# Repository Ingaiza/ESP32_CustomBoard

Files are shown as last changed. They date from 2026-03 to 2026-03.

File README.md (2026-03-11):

# Custom ESP32-C3 Development Board

## Overview
This repository contains the KiCad PCB design files for a custom development board powered by the ESP32-C3 microcontroller. This board integrates essential environmental sensing, audio input, and power management features. It serves as a robust hardware foundation for developing advanced embedded systems and IoT devices.

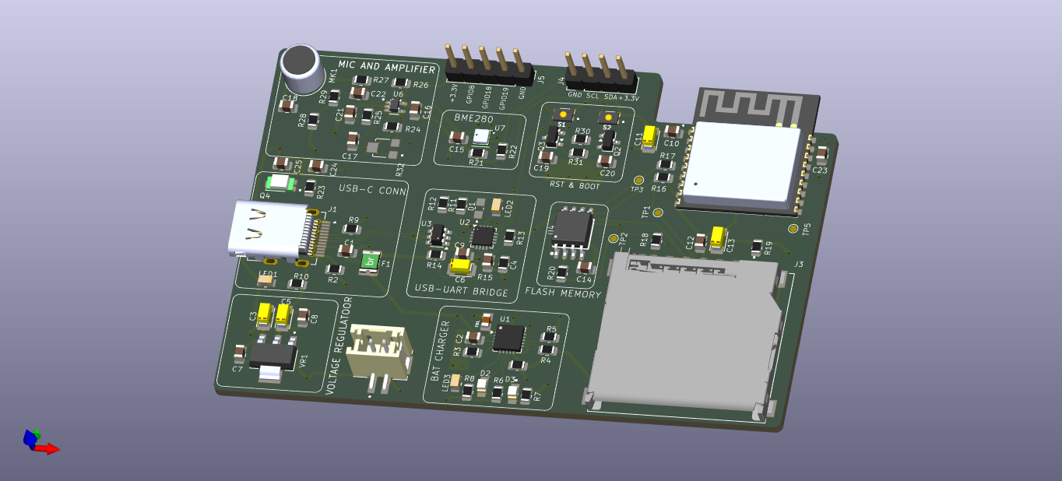
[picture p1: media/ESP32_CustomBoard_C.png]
Board 3D View


## Hardware Features

* **Microcontroller**: Powered by the ESP32-C3-WROOM-02-H4 module, offering Wi-Fi and Bluetooth LE connectivity.
* **Power Management**: 
    * Modern USB-C connector interface.
    * Onboard 3.3V voltage regulation via the LM1117MPX-3.3 LDO.
    * Integrated LiPo battery charging circuit utilizing the MCP73871 IC.
* **USB-to-UART Interface**: Features the CP2102N bridge for reliable serial communication and seamless flashing.
* **Memory & Storage**:
    * External 32Mb (4MB) W25Q32JVSSIQ Flash memory.
    * Dedicated MicroSD card circuit for extensive data logging.
* **Integrated Sensors**:
    * **BME280**: Environmental sensor for capturing temperature, humidity, and barometric pressure data.
    * **TEMT6000**: Ambient light sensor for environmental illumination tracking.
    * **Audio**: Electret microphone (CMC-5042PF-AC) paired with a MAX4466EXK operational amplifier for high-quality audio input.
* **User Interface & Expansion**:
    * Auto-program circuitry equipped with standard Boot and Reset tactile buttons.
    * Dedicated I2C connector optimized for OLED displays.
    * Accessible remaining GPIO breakout headers for rapid prototyping.

## Visuals & Documentation

### Top View
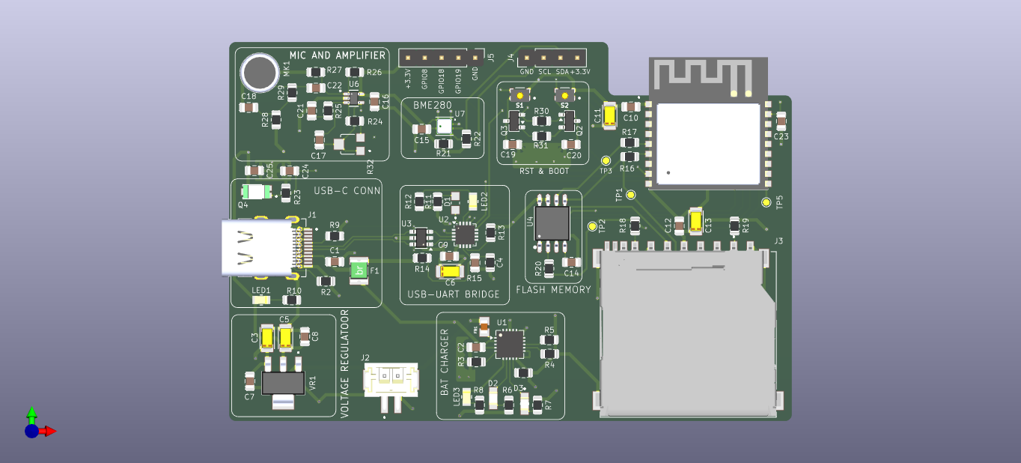
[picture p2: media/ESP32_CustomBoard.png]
Board Top View


### Bottom View Routing
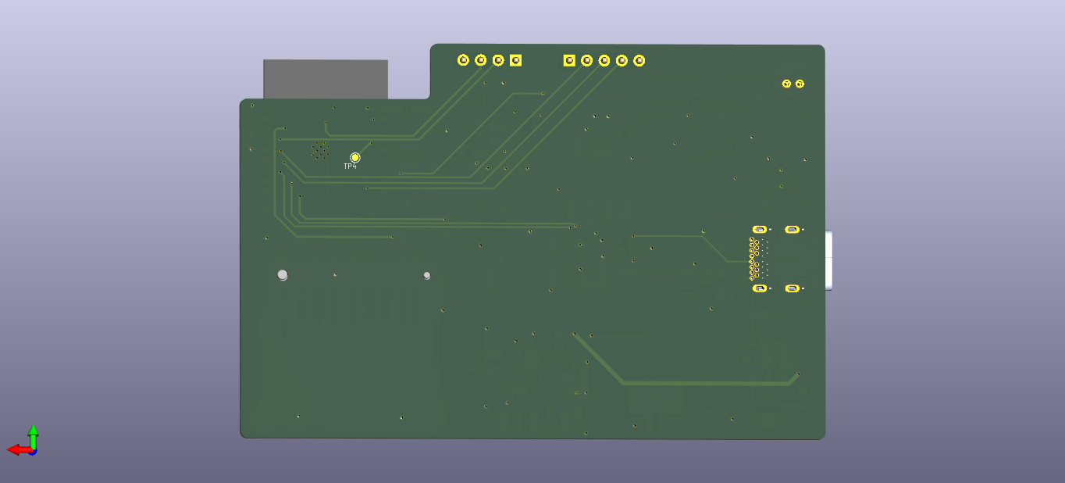
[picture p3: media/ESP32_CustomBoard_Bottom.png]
Board Bottom View


### Schematic
The complete circuit design can be viewed here: [Schematic PDF](media/Shematic.pdf)

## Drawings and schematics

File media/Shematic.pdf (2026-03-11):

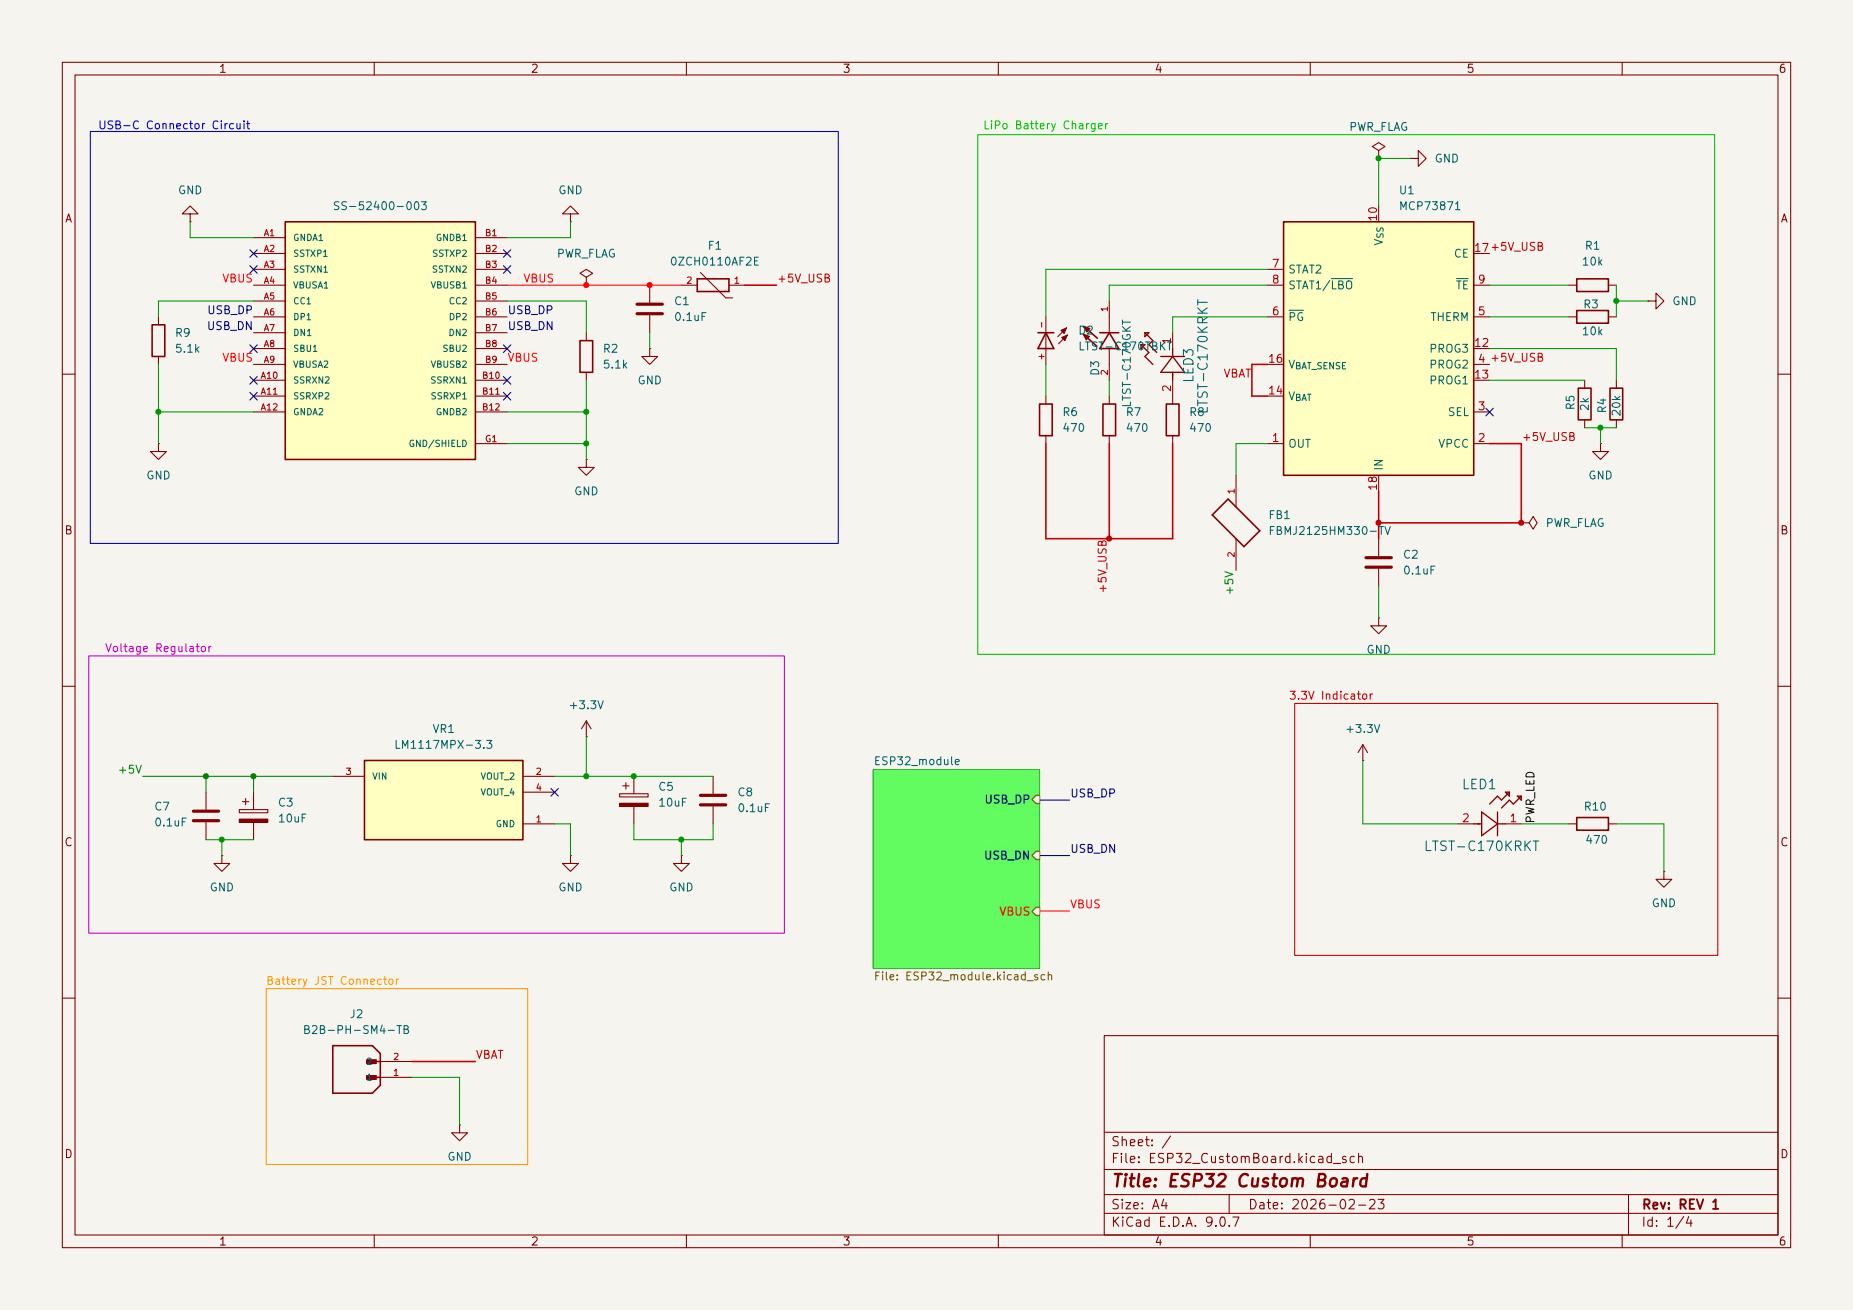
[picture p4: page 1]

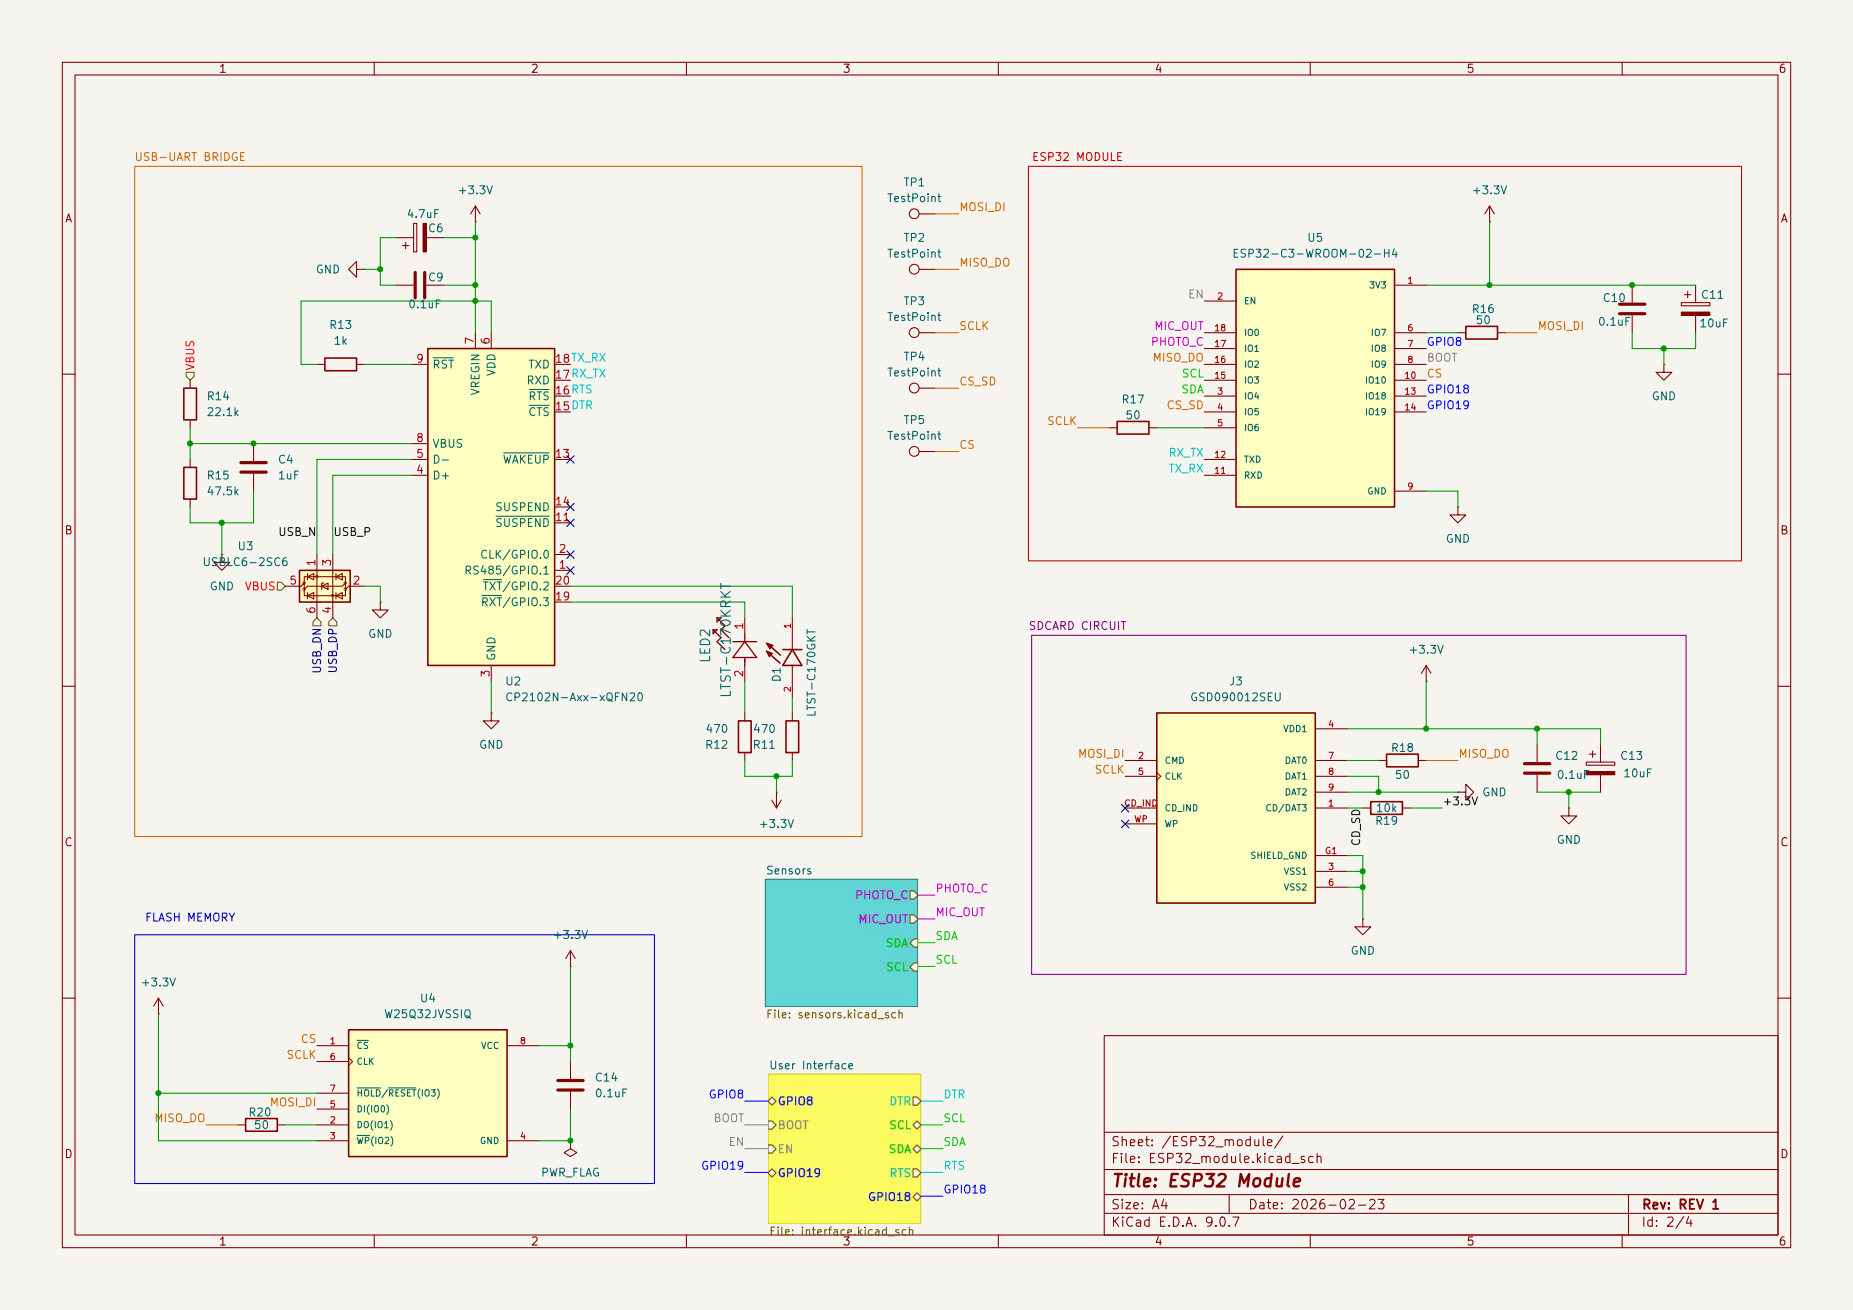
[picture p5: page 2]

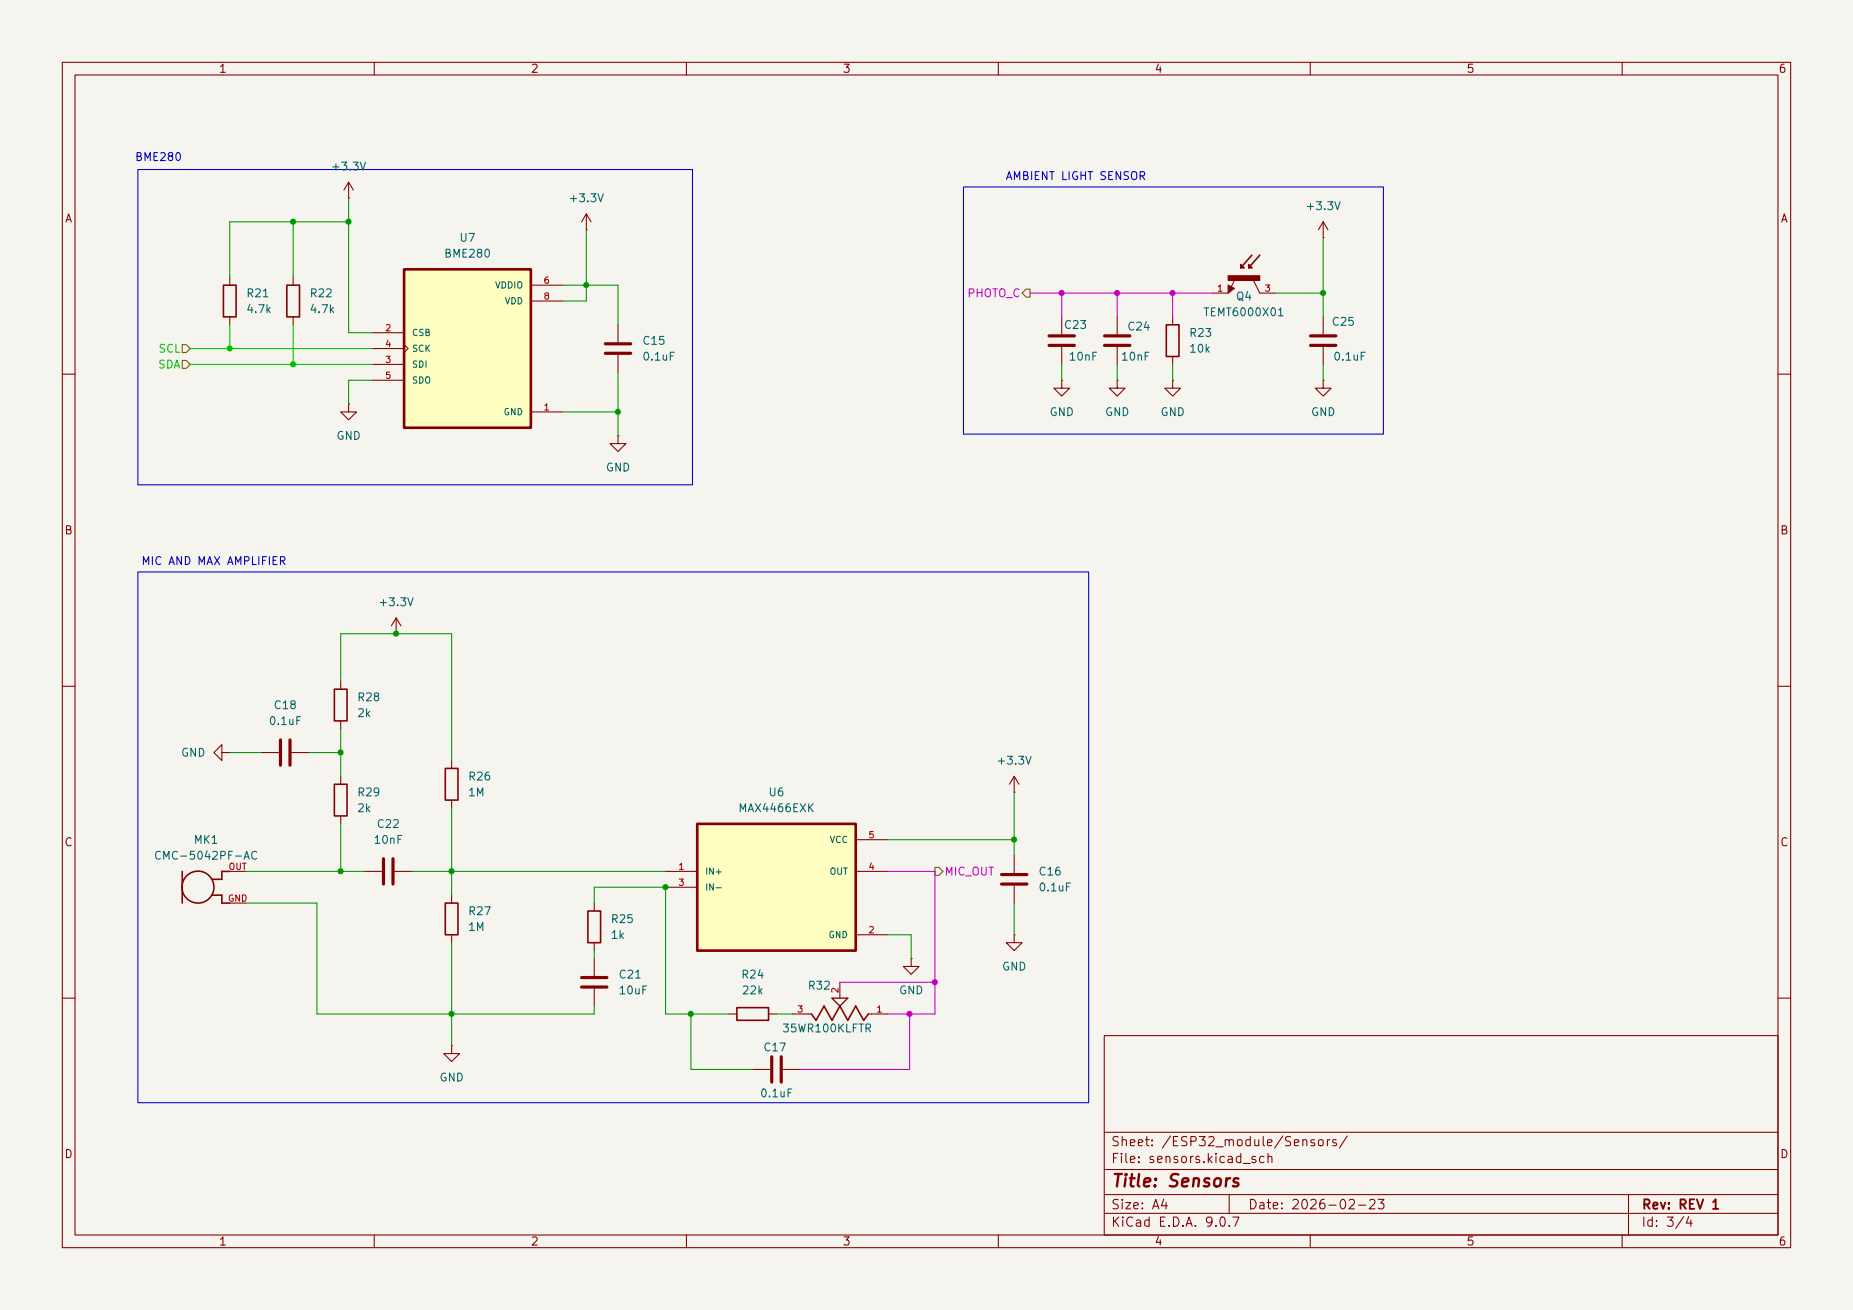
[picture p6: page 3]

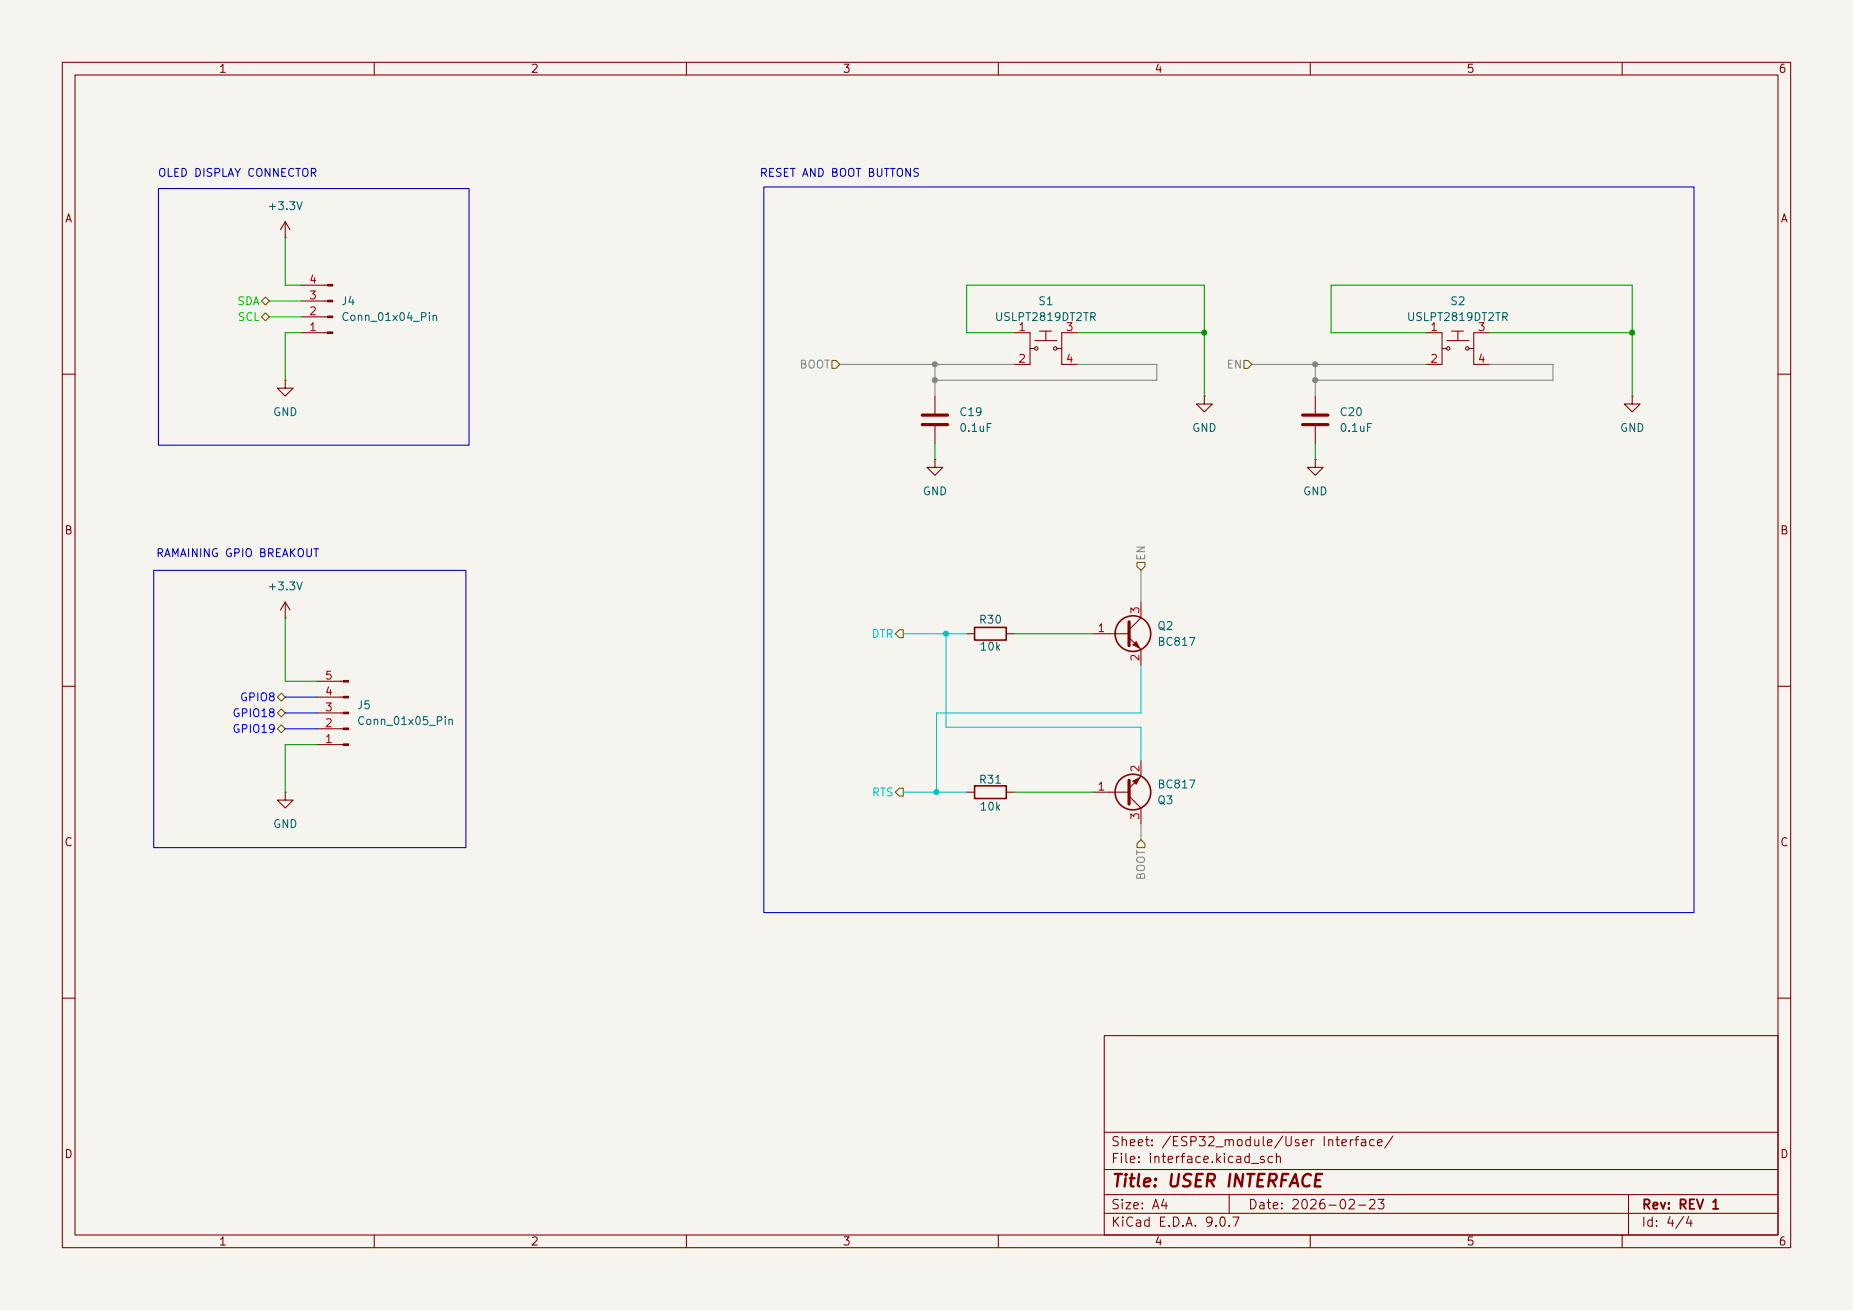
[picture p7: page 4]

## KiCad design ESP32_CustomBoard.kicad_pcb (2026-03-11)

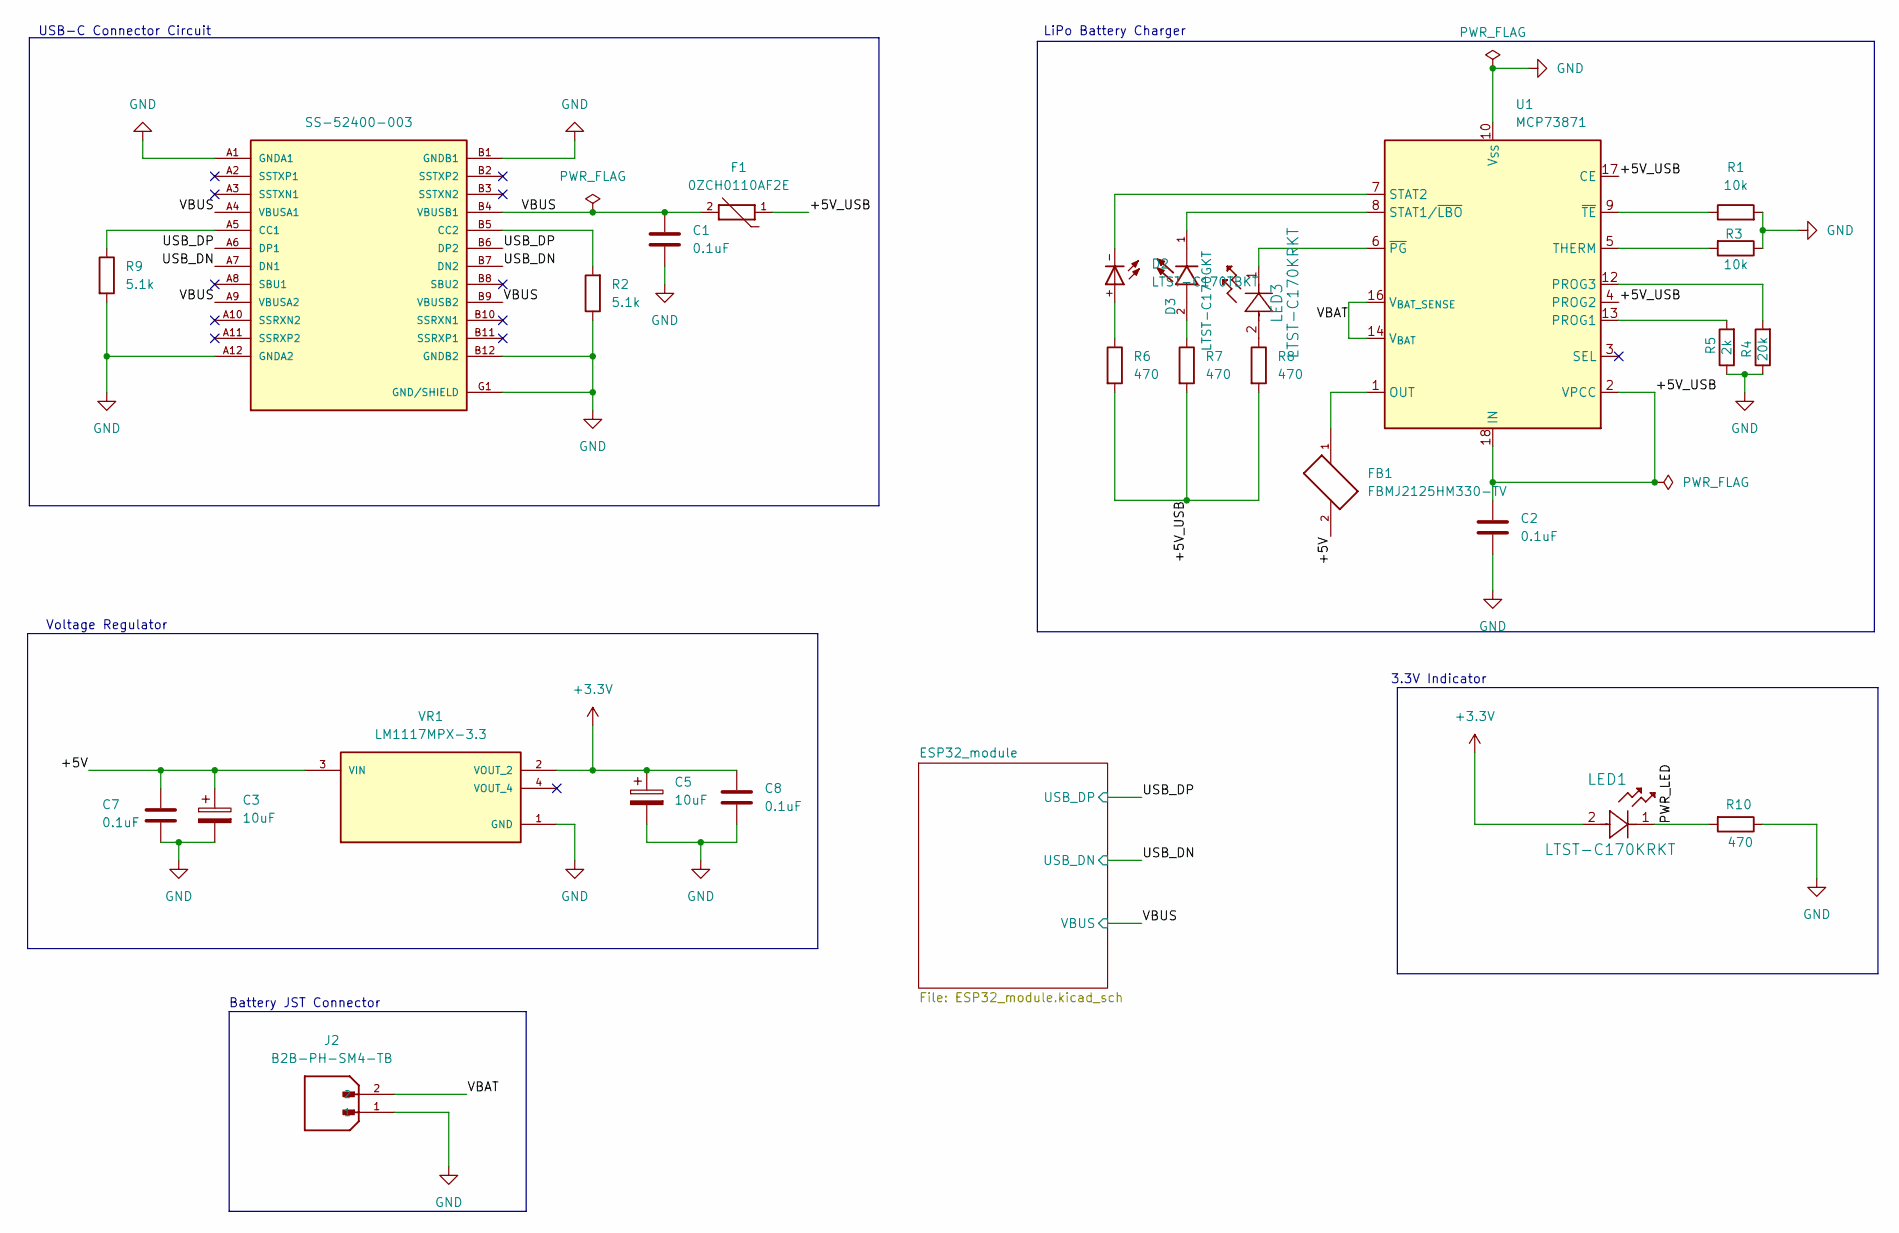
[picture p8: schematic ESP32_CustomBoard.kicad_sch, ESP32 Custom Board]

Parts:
C1, C2, C7, C8: 0.1uF; C_0805_2012Metric
C3, C5: 10uF; RESC3216X125N
D2: LTST-C170TBKT; DIOC200X125X110
D3: LTST-C170GKT; LED_LTST-C170GKT; PARTREV I
F1: 0ZCH0110AF2E; FUSC3225X100N; PARTREV Apr2023
FB1: FBMJ2125HM330-TV; BEADC2012X105N
J1: SS-52400-003; BELFUSE_SS-52400-003; PARTREV A0
J2: B2B-PH-SM4-TB; JST_B2B-PH-SM4-TB; PARTREV N/A
LED1, LED3: LTST-C170KRKT; LED_LTST-C170KRKT_LTO
R1, R3: 10k; R_0805_2012Metric
R2, R9: 5.1k; R_0805_2012Metric
R4: 20k; R_0805_2012Metric
R5: 2k; R_0805_2012Metric
R6, R7, R8, R10: 470; R_0805_2012Metric
U1: MCP73871; QFN-20-1EP_4x4mm_P0.5mm_EP2.5x2.5mm
VR1: LM1117MPX-3.3; VREG_LM1117MPX-3.3; PARTREV O

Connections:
+3.3V: C5.1, C8.1, LED1.2, VR1.2 (VOUT_2); also elsewhere on the board
/+5V: C3.1, C7.1, FB1.2, VR1.3 (VIN)
/+5V_USB: C2.1, F1.1, R6.2, R7.2, R8.2, U1.2 (VPCC), U1.4 (PROG2), U1.17 (CE), U1.18 (IN), U1.19 (IN)
/PWR_LED: LED1.1, R10.2
/USB_DN: J1.A7 (DN1), J1.B7 (DN2); also elsewhere on the board
/USB_DP: J1.A6 (DP1), J1.B6 (DP2); also elsewhere on the board
/VBAT: J2.2, U1.14 (V_{BAT}), U1.15 (V_{BAT}), U1.16 (V_{BAT_SENSE})
/VBUS: C1.1, F1.2, J1.A4 (VBUSA1), J1.A9 (VBUSA2), J1.B4 (VBUSB1), J1.B9 (VBUSB2); also elsewhere on the board
GND: C1.2, C2.2, C3.2, C5.2, C7.2, C8.2, J1.A1 (GNDA1), J1.A12 (GNDA2), J1.B1 (GNDB1), J1.B12 (GNDB2), J1.G1 (GND/SHIELD), J1.G2 (GND/SHIELD), J1.G3 (GND/SHIELD), J1.G4 (GND/SHIELD), J1.S1 (GND/SHIELD), J1.S2 (GND/SHIELD), J1.S3 (GND/SHIELD), J1.S4 (GND/SHIELD), J2.1, R1.2, R2.1, R3.1, R4.1, R5.1, R9.2, R10.1, U1.10 (V_{SS}), U1.11 (V_{SS}), U1.21 (V_{SS}), VR1.1 (GND); also elsewhere on the board
unnamed: D2.+, R6.1
unnamed: D3.2, R7.1
unnamed: FB1.1, U1.1 (OUT), U1.20 (OUT)
unnamed: J1.A5 (CC1), R9.1
unnamed: J1.B5 (CC2), R2.2
unnamed: LED3.2, R8.1
unnamed: R5.2, U1.13 (PROG1)
unnamed: R4.2, U1.12 (PROG3)
unnamed: D3.1, U1.8 (STAT1/~LBO)
unnamed: D2.-, U1.7 (STAT2)
unnamed: R3.2, U1.5 (THERM)
unnamed: LED3.1, U1.6 (~PG)
unnamed: R1.1, U1.9 (~TE)

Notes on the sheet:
USB-C Connector Circuit
Voltage Regulator
LiPo Battery Charger
Battery JST Connector
3.3V Indicator

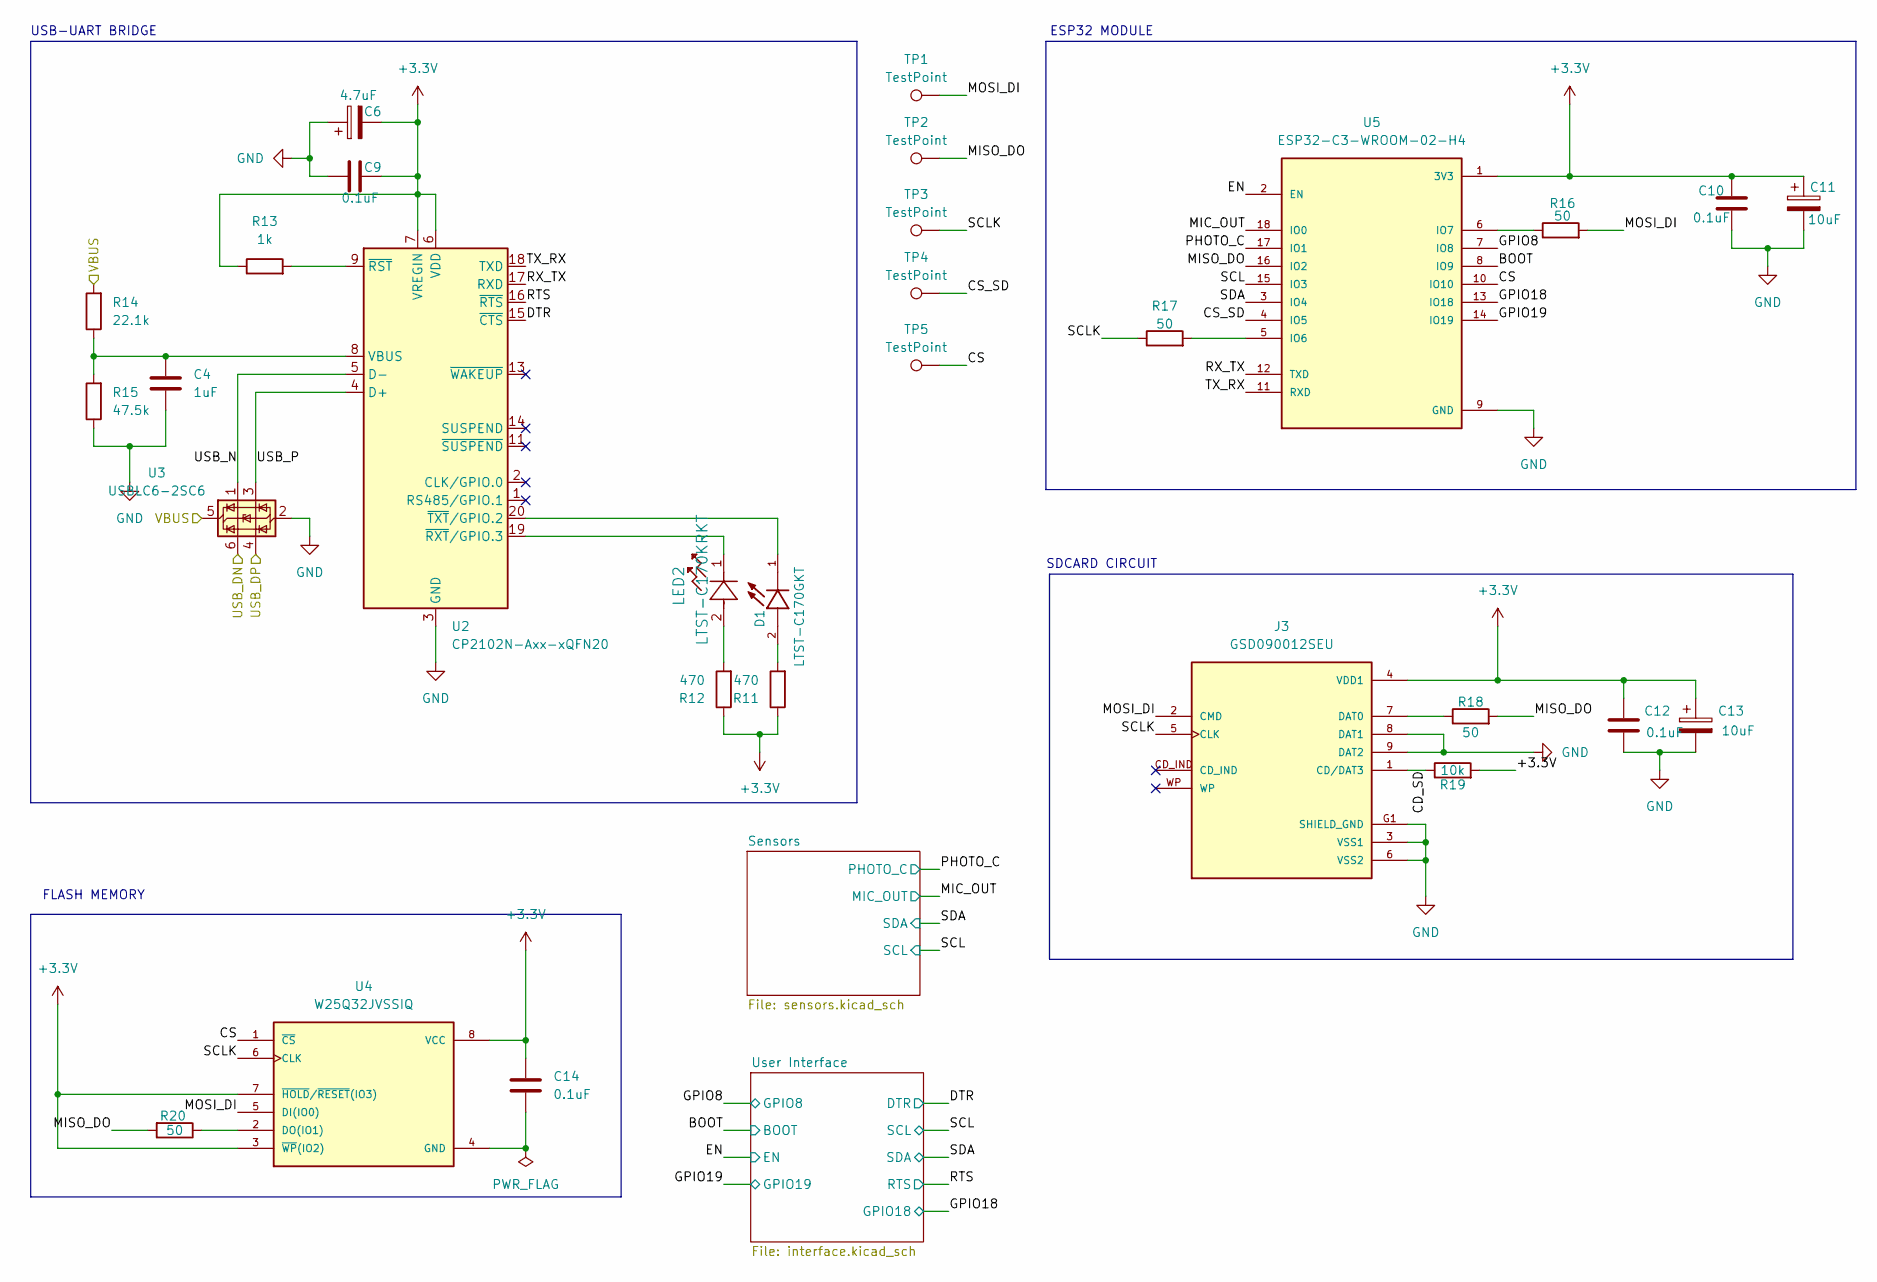
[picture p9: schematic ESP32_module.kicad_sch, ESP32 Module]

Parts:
C4: 1uF; C_0805_2012Metric
C6: 4.7uF; RESC3216X125N
C9, C10, C12, C14: 0.1uF; C_0805_2012Metric
C11, C13: 10uF; RESC3216X125N
D1: LTST-C170GKT; LED_LTST-C170GKT; PARTREV I
J3: GSD090012SEU; AMPHENOL_GSD090012SEU; PARTREV E
LED2: LTST-C170KRKT; LED_LTST-C170KRKT_LTO
R11, R12: 470; R_0805_2012Metric
R13: 1k; R_0805_2012Metric
R14: 22.1k; R_0805_2012Metric
R15: 47.5k; R_0805_2012Metric
R16, R17, R18, R20: 50; R_0805_2012Metric
R19: 10k; R_0805_2012Metric
TP1, TP2, TP3, TP4, TP5: TestPoint; TestPoint_Pad_D1.0mm
U2: CP2102N-Axx-xQFN20; SiliconLabs_QFN-20-1EP_3x3mm_P0.5mm_EP1.8x1.8mm
U3: USBLC6-2SC6; SOT-23-6
U4: W25Q32JVSSIQ; SOIC127P790X216-8N; M_PART_NUMBER W25QXX
U5: ESP32-C3-WROOM-02-H4; MODULE_ESP32-C3-WROOM-02-H4

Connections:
+3.3V: C6.2, C9.2, C10.2, C11.1, C12.1, C13.1, C14.1, J3.4 (VDD1), R11.1, R12.1, R13.1, R19.2, U2.6 (VDD), U2.7 (VREGIN), U4.3 (~WP(IO2)), U4.7 (~HOLD/~RESET(IO3)), U4.8 (VCC), U5.1 (3V3); also elsewhere on the board
/ESP32_module/BOOT: U5.8 (IO9); also elsewhere on the board
/ESP32_module/CD_SD: J3.1 (CD/DAT3), R19.1
/ESP32_module/CS: TP5.1, U4.1 (~CS), U5.10 (IO10)
/ESP32_module/CS_SD: TP4.1, U5.4 (IO5)
/ESP32_module/DTR: U2.15 (~CTS); also elsewhere on the board
/ESP32_module/EN: U5.2 (EN); also elsewhere on the board
/ESP32_module/GPIO8: U5.7 (IO8); also elsewhere on the board
/ESP32_module/GPIO18: U5.13 (IO18); also elsewhere on the board
/ESP32_module/GPIO19: U5.14 (IO19); also elsewhere on the board
/ESP32_module/MIC_OUT: U5.18 (IO0); also elsewhere on the board
/ESP32_module/MISO_DO: R18.2, R20.2, TP2.1, U5.16 (IO2)
/ESP32_module/MOSI_DI: J3.2 (CMD), R16.2, TP1.1, U4.5 (DI(IO0))
/ESP32_module/PHOTO_C: U5.17 (IO1); also elsewhere on the board
/ESP32_module/RTS: U2.16 (~RTS); also elsewhere on the board
/ESP32_module/RX_TX: U2.17 (RXD), U5.12 (TXD)
/ESP32_module/SCL: U5.15 (IO3); also elsewhere on the board
/ESP32_module/SCLK: J3.5 (CLK), R17.1, TP3.1, U4.6 (CLK)
/ESP32_module/SDA: U5.3 (IO4); also elsewhere on the board
/ESP32_module/TX_RX: U2.18 (TXD), U5.11 (RXD)
/ESP32_module/USB_N: U2.5 (D-), U3.1 (I/O1)
/ESP32_module/USB_P: U2.4 (D+), U3.3 (I/O2)
/USB_DN: U3.6 (I/O1); also elsewhere on the board
/USB_DP: U3.4 (I/O2); also elsewhere on the board
/VBUS: R14.2, U3.5 (VBUS); also elsewhere on the board
GND: C4.2, C6.1, C9.1, C10.1, C11.2, C12.2, C13.2, J3.3 (VSS1), J3.6 (VSS2), J3.8 (DAT1), J3.9 (DAT2), J3.G1 (SHIELD_GND), J3.G2 (SHIELD_GND), J3.G3 (SHIELD_GND), J3.G4 (SHIELD_GND), R15.1, U2.3 (GND), U2.12 (GND), U2.21 (GND), U3.2 (GND), U5.9 (GND), U5.19 (GND), U5.20 (GND), U5.21 (GND), U5.22 (GND), U5.23 (GND), U5.24 (GND), U5.25 (GND), U5.26 (GND), U5.27 (GND), U5.28 (GND), U5.29 (GND), U5.30 (GND), U5.31 (GND), U5.32 (GND), U5.33 (GND), U5.34 (GND), U5.35 (GND), U5.36 (GND), U5.37 (GND), U5.38 (GND), U5.39 (GND); also elsewhere on the board
unnamed: D1.2, R11.2
unnamed: J3.7 (DAT0), R18.1
unnamed: LED2.2, R12.2
unnamed: C4.1, R14.1, R15.2, U2.8 (VBUS)
unnamed: R13.2, U2.9 (~RST)
unnamed: LED2.1, U2.19 (~RXT/GPIO.3)
unnamed: D1.1, U2.20 (~TXT/GPIO.2)
unnamed: R20.1, U4.2 (DO(IO1))
unnamed: C14.2, U4.4 (GND)
unnamed: R17.2, U5.5 (IO6)
unnamed: R16.1, U5.6 (IO7)

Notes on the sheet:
SDCARD CIRCUIT
ESP32 MODULE
USB-UART BRIDGE
FLASH MEMORY

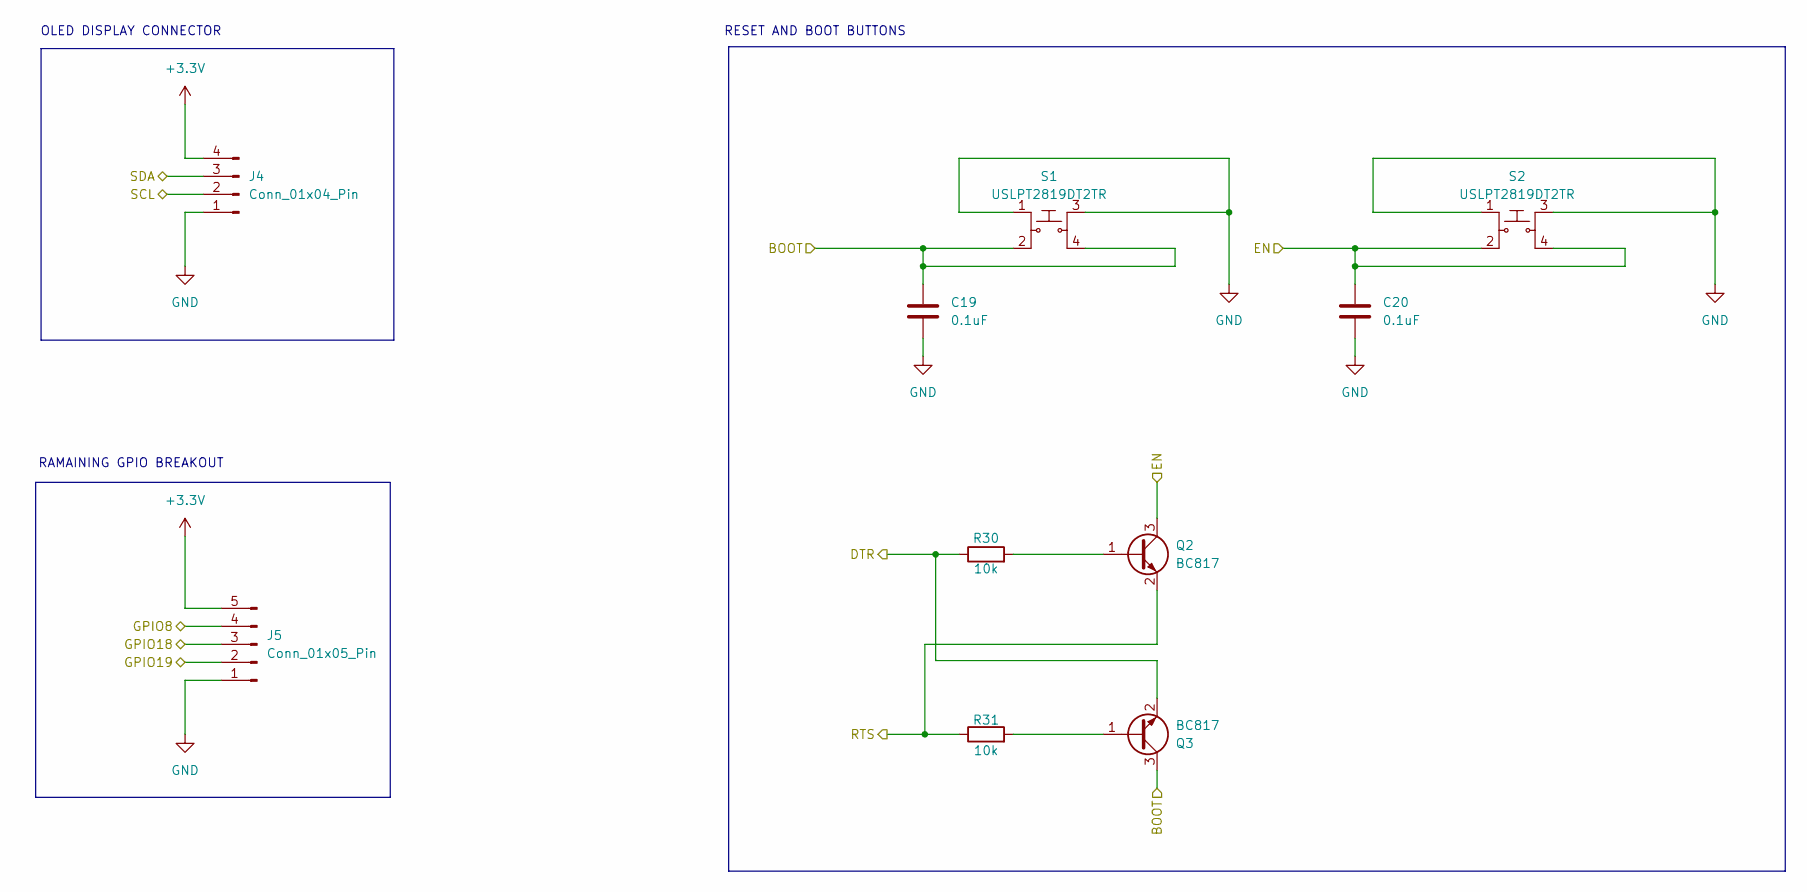
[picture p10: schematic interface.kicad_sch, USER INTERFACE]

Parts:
C19, C20: 0.1uF; C_0805_2012Metric
J4: Conn_01x04_Pin; PinHeader_1x04_P2.54mm_Vertical
J5: Conn_01x05_Pin; PinHeader_1x05_P2.54mm_Vertical
Q2, Q3: BC817; SOT-23
R30, R31: 10k; R_0805_2012Metric
S1, S2: USLPT2819DT2TR; SW_USLPT2819DT2TR; PARTREV P; Digi-Key_PN EG4621CT-ND

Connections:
+3.3V: J4.4, J5.5; also elsewhere on the board
/ESP32_module/BOOT: C19.1, Q3.3 (C), S1.2, S1.4; also elsewhere on the board
/ESP32_module/DTR: Q3.2 (E), R30.1; also elsewhere on the board
/ESP32_module/EN: C20.1, Q2.3 (C), S2.2, S2.4; also elsewhere on the board
/ESP32_module/GPIO8: J5.4; also elsewhere on the board
/ESP32_module/GPIO18: J5.3; also elsewhere on the board
/ESP32_module/GPIO19: J5.2; also elsewhere on the board
/ESP32_module/RTS: Q2.2 (E), R31.1; also elsewhere on the board
/ESP32_module/SCL: J4.2; also elsewhere on the board
/ESP32_module/SDA: J4.3; also elsewhere on the board
GND: C19.2, C20.2, J4.1, J5.1, S1.1, S1.3, S2.1, S2.3; also elsewhere on the board
unnamed: Q2.1 (B), R30.2
unnamed: Q3.1 (B), R31.2

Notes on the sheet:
OLED DISPLAY CONNECTOR
RESET AND BOOT BUTTONS
RAMAINING GPIO BREAKOUT

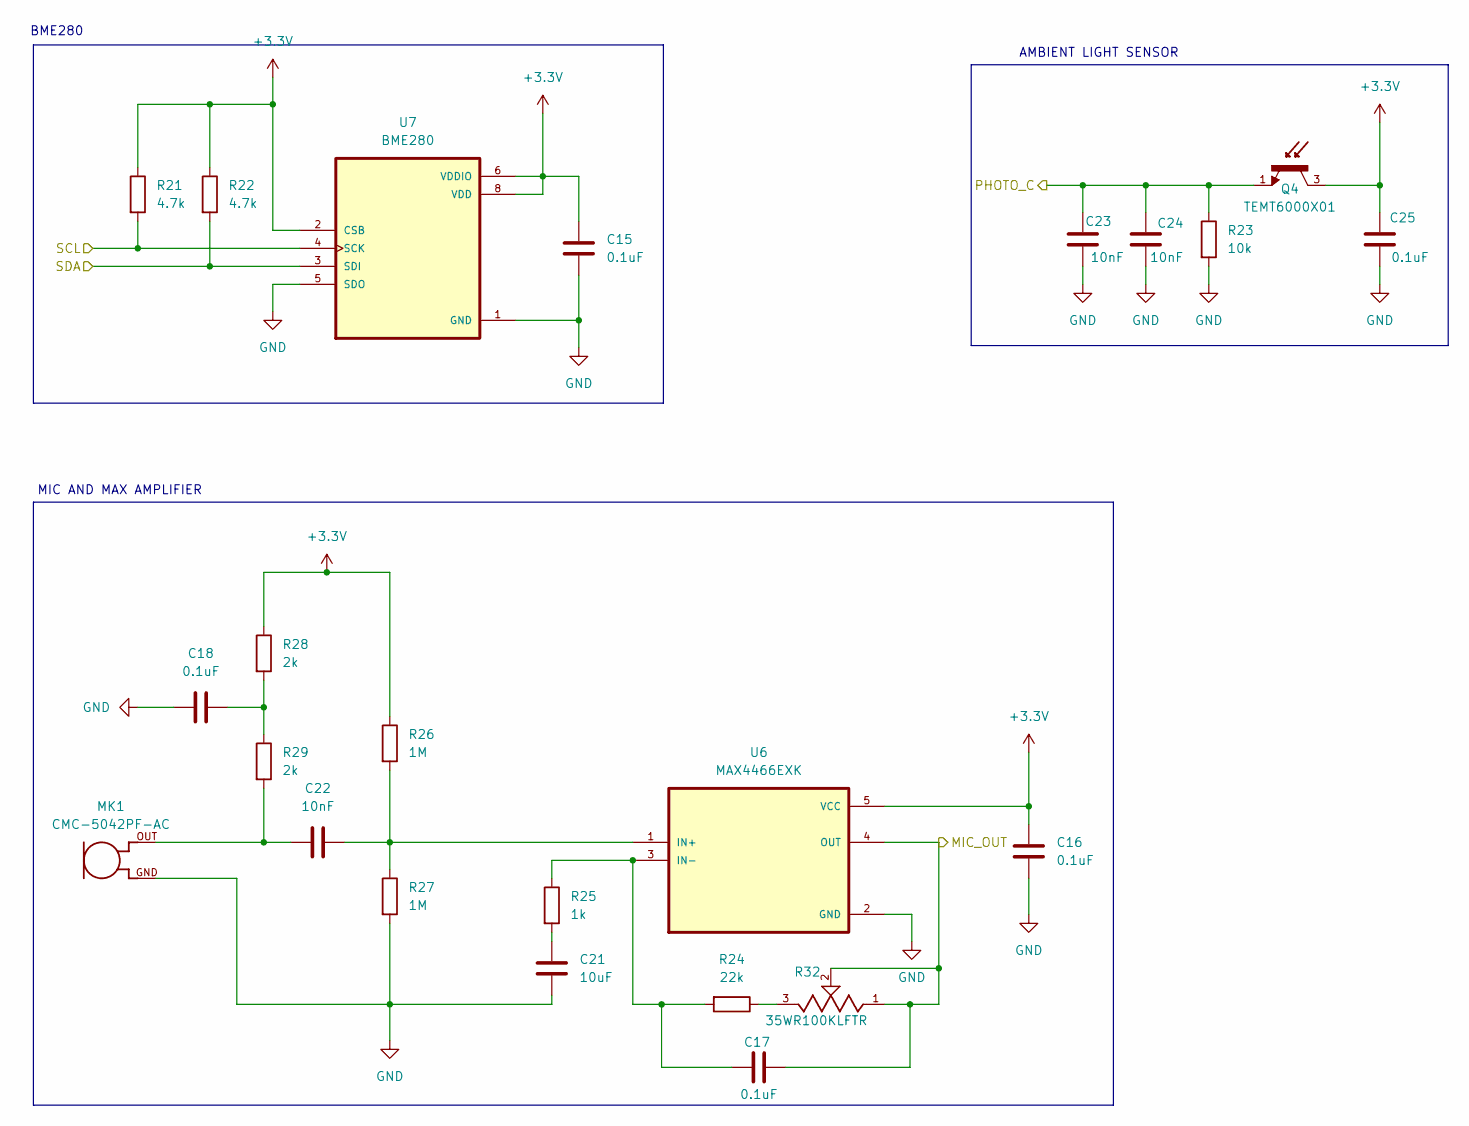
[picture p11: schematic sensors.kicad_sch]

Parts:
C15, C16, C17, C18, C25: 0.1uF; C_0805_2012Metric
C21: 10uF; C_0805_2012Metric
C22, C23, C24: 10nF; C_0805_2012Metric
MK1: CMC-5042PF-AC; CUI_CMC-5042PF-AC
Q4: TEMT6000X01; TRANS_TEMT6000X01; PARTREV 1.9
R21, R22: 4.7k; R_0805_2012Metric
R23: 10k; R_0805_2012Metric
R24: 22k; R_0805_2012Metric
R25: 1k; R_0805_2012Metric
R26, R27: 1M; R_0805_2012Metric
R28, R29: 2k; R_0805_2012Metric
R32: 35WR100KLFTR; TRIM_35WR100KLFTR; PARTREV D
U6: MAX4466EXK; SOT65P210X110-5N
U7: BME280; PSON65P250X250X100-8N

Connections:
+3.3V: C15.1, C16.1, C25.1, Q4.3, R21.1, R22.1, R26.1, R28.1, U6.5 (VCC), U7.2 (CSB), U7.6 (VDDIO), U7.8 (VDD); also elsewhere on the board
/ESP32_module/MIC_OUT: C17.2, R32.1, R32.2, U6.4 (OUT); also elsewhere on the board
/ESP32_module/PHOTO_C: C23.1, C24.1, Q4.1, R23.1; also elsewhere on the board
/ESP32_module/SCL: R21.2, U7.4 (SCK); also elsewhere on the board
/ESP32_module/SDA: R22.2, U7.3 (SDI); also elsewhere on the board
GND: C15.2, C16.2, C18.1, C21.2, C23.2, C24.2, C25.2, MK1.GND, R23.2, R27.2, U6.2 (GND), U7.1 (GND), U7.5 (SDO), U7.7 (GND); also elsewhere on the board
unnamed: C18.2, R28.2, R29.1
unnamed: C21.1, R25.2
unnamed: C22.1, MK1.OUT, R29.2
unnamed: R24.1, R32.3
unnamed: C22.2, R26.2, R27.1, U6.1 (IN+)
unnamed: C17.1, R24.2, R25.1, U6.3 (IN-)

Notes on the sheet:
AMBIENT LIGHT SENSOR
BME280
MIC AND MAX AMPLIFIER

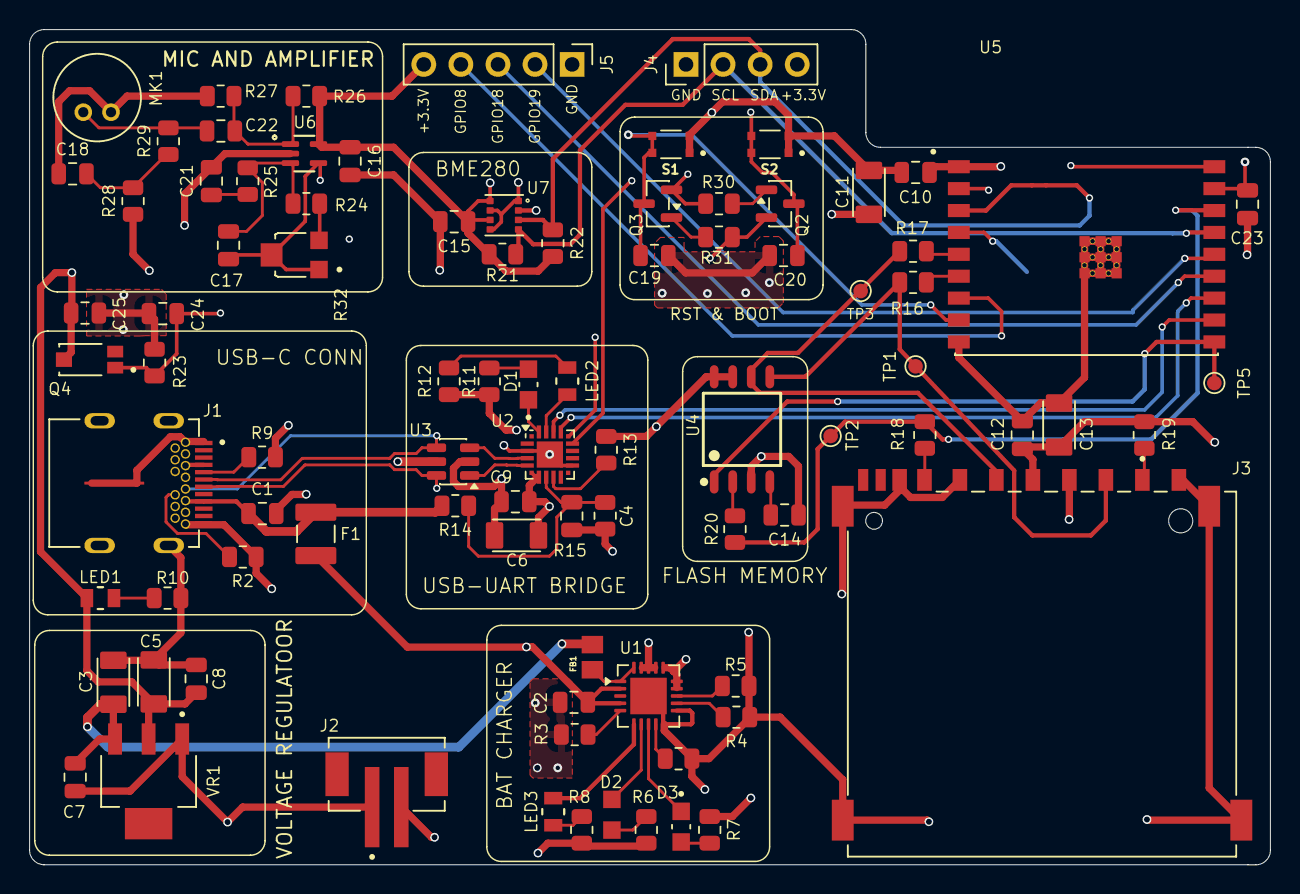
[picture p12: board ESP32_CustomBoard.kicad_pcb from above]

Board: 4 copper layers, 85.0 x 57.2 mm, 89 parts (1 on the bottom side), 62 nets.

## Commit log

2026-02-23 Completed Sheet 1 - Power Supply
    [ESP32_CustomBoard.kicad_pcb, ESP32_CustomBoard.kicad_sch]
2026-02-23 Completed Sheet 2- ESP32 Module
    [ESP32_CustomBoard.kicad_sch, ESP32_module.kicad_sch]
2026-02-23 Completed Sheet 3- Sensors and Sheet 4- User Interface
    [ESP32_CustomBoard.kicad_sch, ESP32_module.kicad_sch, interface.kicad_sch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]
2026-02-24 Completed Schematic Layout
    [ESP32_CustomBoard.kicad_sch, ESP32_module.kicad_sch, interface.kicad_sch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]
2026-02-24 Net Class Assignment. Created Power, USB_Comms,UART, SPI, I2C, Sensors and CMD Net Classes and assigned nets
    [ESP32_module.kicad_sch, interface.kicad_sch, sensors.kicad_sch]
2026-02-25 Fixed Audio Amp Circuit
    [ESP32_CustomBoard.kicad_sch, ESP32_module.kicad_sch, interface.kicad_sch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]
2026-02-25 Fixed the Footprint assignment nonsense
    [ESP32_CustomBoard.kicad_sch, ESP32_module.kicad_sch, interface.kicad_sch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]
2026-02-25 Fixed ONE MORE Footprint misassignment
    [ESP32_module.kicad_sch]
2026-02-26 Layout Placement
    [ESP32_CustomBoard.kicad_pcb]
2026-02-27 Power copper zones and Placement complete
    [ESP32_CustomBoard.kicad_sch, ESP32_module.kicad_sch, interface.kicad_sch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]
2026-02-27 Completed Routing
    [ESP32_CustomBoard.kicad_pcb]
2026-02-27 3D models added
    [ESP32_CustomBoard.kicad_pcb]
2026-03-10 fixed errors, completed silkscreen and 3D assignment
2026-03-10 Schematic Fixes
    [ESP32_CustomBoard.csv, ESP32_CustomBoard.kicad_pcb]
2026-03-11 Completed layout fix
    [ESP32_CustomBoard.kicad_pcb, ESP32_CustomBoard.kicad_sch, ESP32_module.kicad_sch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]
2026-03-11 created media dir
    [ESP32_CustomBoard.csv]
2026-03-11 Fixed MIC silkscreen and updated media images
    [ESP32_CustomBoard.kicad_pcb]
